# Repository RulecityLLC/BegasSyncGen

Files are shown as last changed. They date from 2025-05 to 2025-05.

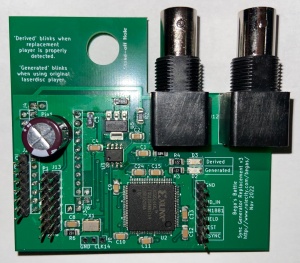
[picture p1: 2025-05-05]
BegasSyncGenPic.jpg

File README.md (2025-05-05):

# BegasSyncGen
Sync generator replacement for Bega's Battle hardware.  So that Bega's Battle will work with non-original laserdisc players, including Dexter.

# Introduction
For a full explanation, see http://www.rulecity.com/begas/ .

# PCB
I created the PCB with KiCad v5.  I tested the files on KiCad v8 and they seem to work fine.

# VHDL
I've included the VHDL source code programs I wrote for the CPLD.  I built with Xilinx ISE 14.7 which, last I checked, can be obtained for free as a linux VM that runs fine under Windows in VirtualBox.

# Bill of Materials
These are the actual spreadsheets I used when ordering parts for these PCBs.

# Support
If you need help building the VHDL code, programming the CPLDs, or having PCBs made from the KiCad files, I offer commercial support: https://www.daphne-emu.com:9443/mediawiki/index.php/CommercialSupport

--Matt Ownby

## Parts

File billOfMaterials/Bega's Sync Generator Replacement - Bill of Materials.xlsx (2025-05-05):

Quantity | Reference | Manufacturer | Manufacturer Part Number | Distributor | Dist. Part Number | Note
Surface mount
11 | C1, C2, C4, C8, C9, C10, C11, C12, C13, C15, C24 | Wurth | 885012208009 | Digi-Key | 732-8086-1-ND | 0.1 uF
2 | C3, C5 | Vishay | TL3A106K010C2000 | Digi-Key | 718-TL3A106K010C2000CT-ND | 10 uF
1 | D2 | Kingbright Company LLC | APT3216SECK/J3-PRV | Digi-Key | 754-1796-1-ND | "Generated" LED (Red)
1 | D3 | Kingbright Company LLC | APT3216SGC | Digi-Key | 754-1141-1-ND | "Derived" LED (Green)
1 | R1 |  |  | Digi-Key | P680KETR-ND | 680k Ohm
1 | R2 |  |  | Digi-Key | P75ETR-ND | 75 Ohm
2 | R3,R4 |  |  | Digi-Key | P220ETR-ND | 220 Ohm
1 | R6 |  |  | Digi-Key | P1.0KETR-ND | 1k Ohm
1 | U2 |  |  |  |  | XC95144XL-5TQG100C (XC95144XL-10TQG100C is also okay)
1 | U3 |  |  | Digi-Key | 296-47437-2-ND | LM1881
1 | U5 |  |  | Digi-Key | NCP1117LPST33T3GOSCT-ND | 3.3V voltage regulator
1 | X1 |  |  | Digi-Key | 3997-S53305T-14.31818-X-RTR-ND | S53305T-14.31818-X-R
Through hole
1 | C17 |  |  | Digi-Key | 493-15702-ND | 470uF
5 | J1,J7, J2, J8, J10+J9 |  |  | Digi-Key | 952-3302-ND | 1x12
1 | n/a |  |  | Digi-Key | S7045-ND | 1x12 socket
1 | n/a |  |  | Digi-Key | S7044-ND | 1x11 socket
4 | J3,J4,J5,J6 |  |  | Digi-Key | S7000-ND | 1x02 socket
2 | J11,J12 |  |  | Digi-Key | ACX1971-ND | BNC connector
1 | J13 |  |  | Digi-Key | 2057-PH2-14-UA-ND | JTAG Interface
Legend
Substitution is allowed
Substitution is allowed but this may change values of C3 and C5, so be careful
Substitution is allowed but clock accuracy is important

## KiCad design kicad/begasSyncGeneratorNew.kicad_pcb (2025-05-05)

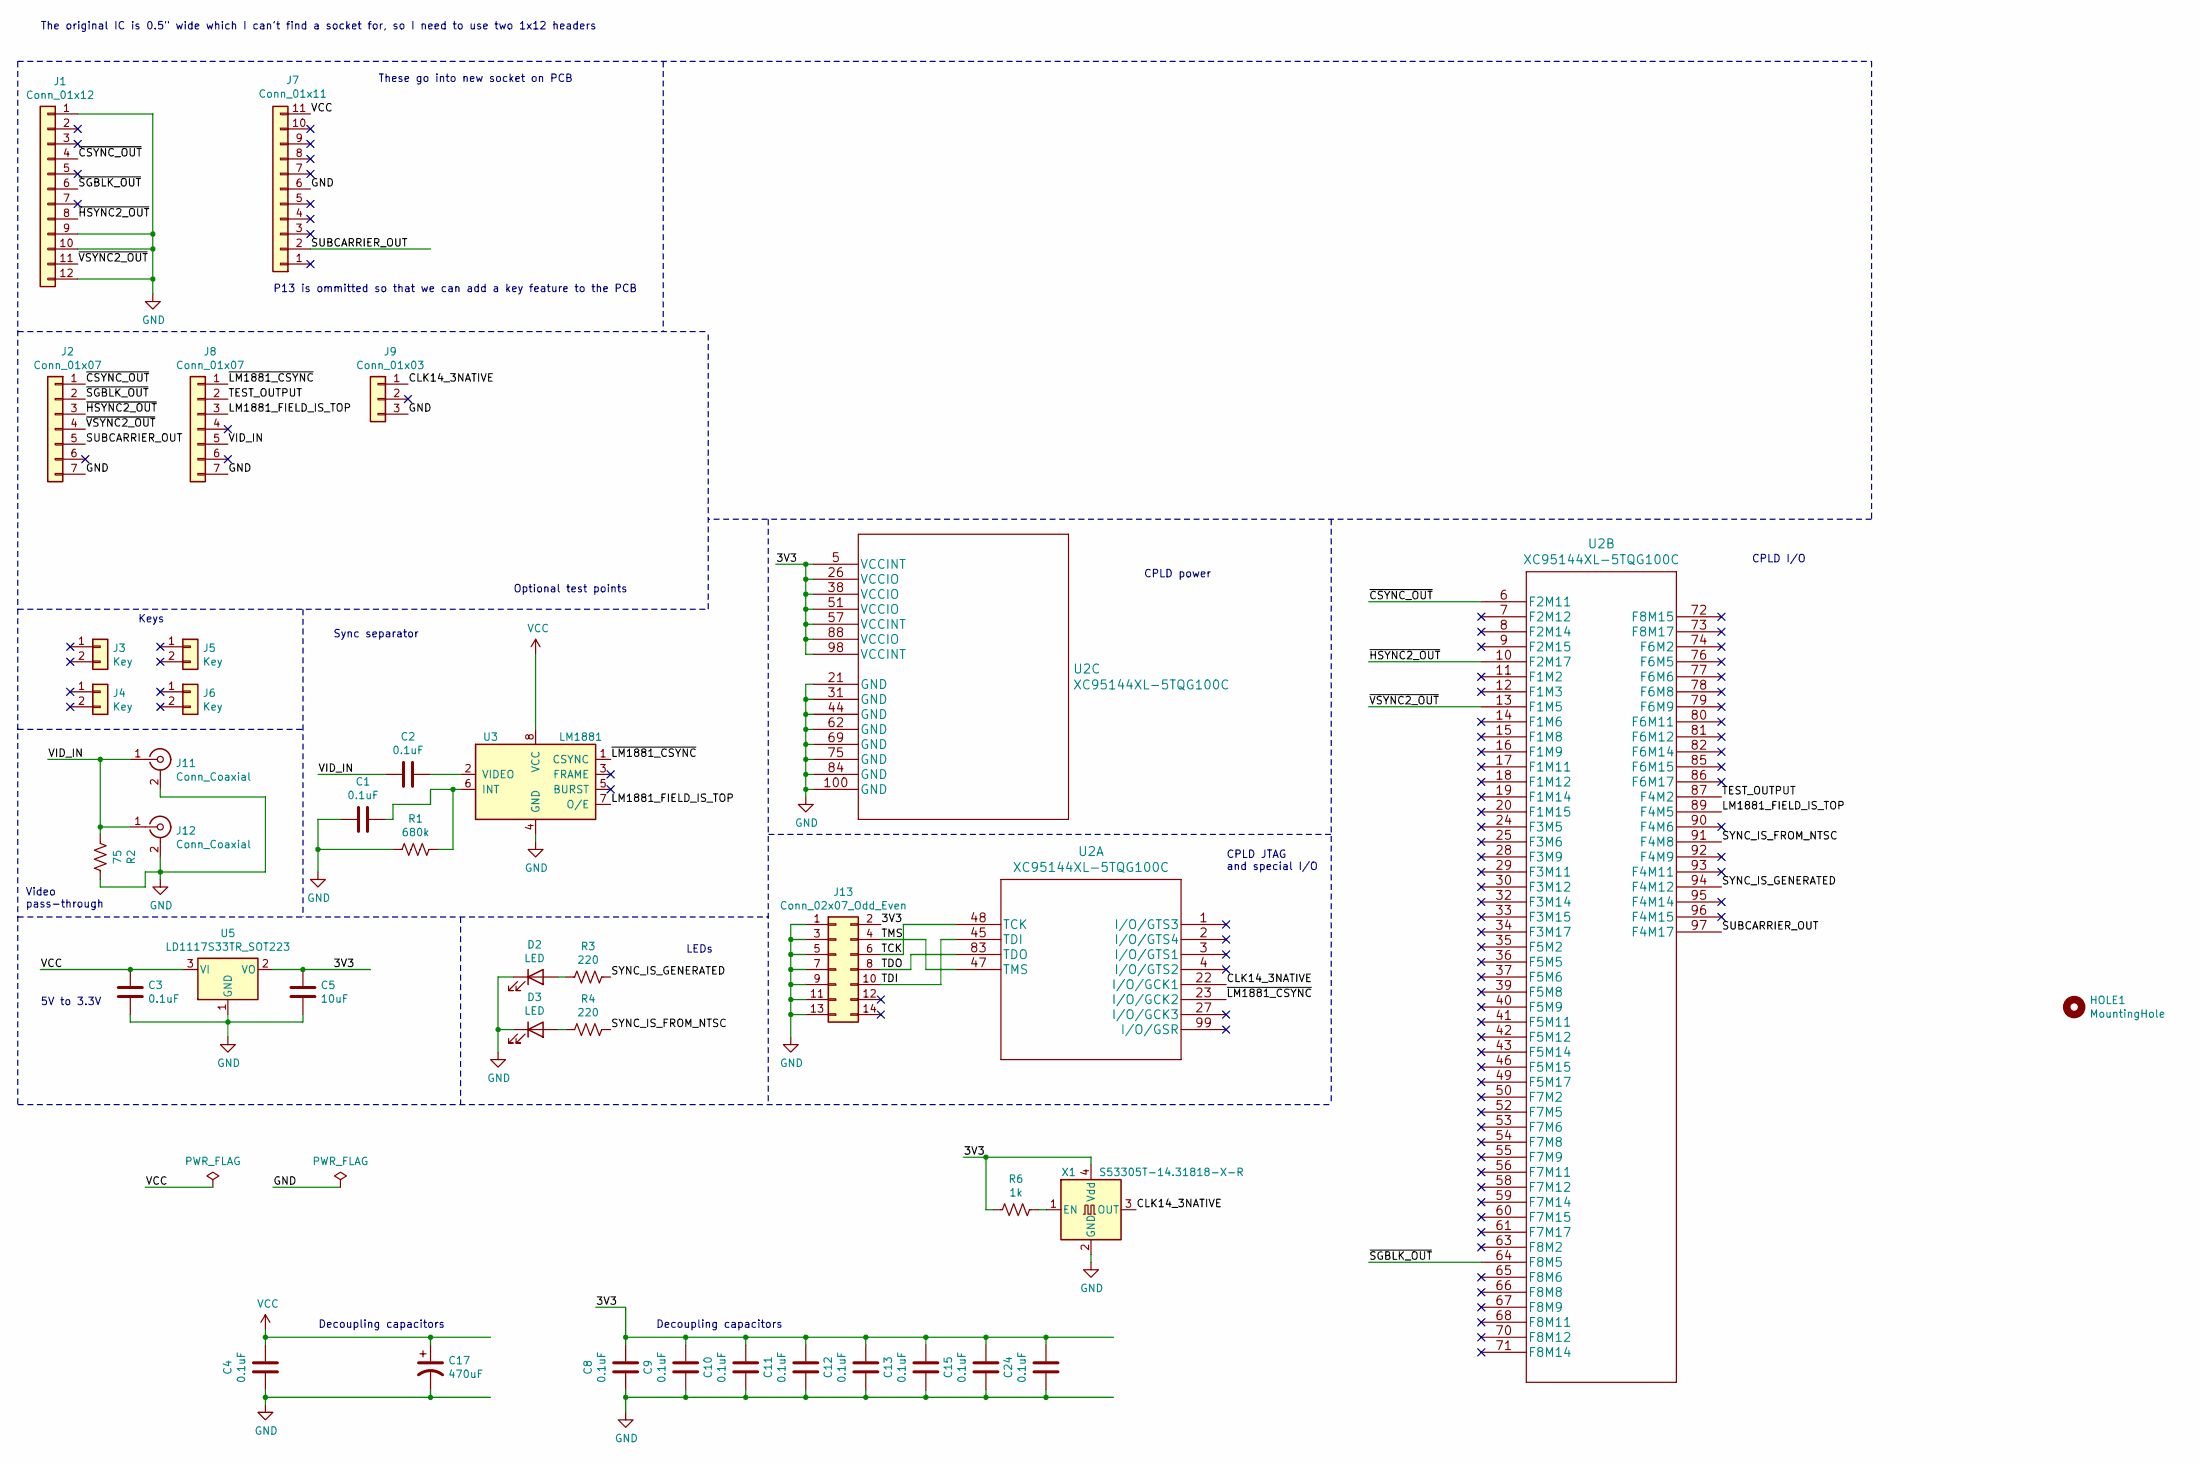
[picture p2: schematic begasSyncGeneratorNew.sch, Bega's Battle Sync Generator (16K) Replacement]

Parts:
C1, C2, C3, C4, C8, C9, C10, C11, C12, C13, C15, C24: 0.1uF; C_1206_3216Metric_Pad1.42x1.75mm_HandSolder
C5: 10uF; C_1206_3216Metric_Pad1.42x1.75mm_HandSolder
C17: 470uF; CP_Radial_D8.0mm_P5.00mm
D2, D3: LED; LED_1206_3216Metric_Pad1.42x1.75mm_HandSolder
HOLE1: MountingHole; MountingHole_8.4mm_M8
J1: Conn_01x12; PinHeader_1x12_P2.54mm_Vertical
J2, J8: Conn_01x07; PinHeader_1x07_P2.54mm_Vertical
J3, J4, J5, J6: Key; PinHeader_1x02_P2.54mm_Vertical
J7: Conn_01x11; PinHeader_1x11_P2.54mm_Vertical
J9: Conn_01x03; PinHeader_1x03_P2.54mm_Vertical
J11, J12: Conn_Coaxial; BNC_Amphenol_B6252HB-NPP3G-50_Horizontal
J13: Conn_02x07_Odd_Even; PinHeader_2x07_P2.54mm_Vertical
R1: 680k; R_1206_3216Metric_Pad1.42x1.75mm_HandSolder
R2: 75; R_1206_3216Metric_Pad1.42x1.75mm_HandSolder
R3, R4: 220; R_1206_3216Metric_Pad1.42x1.75mm_HandSolder
R6: 1k; R_1206_3216Metric_Pad1.42x1.75mm_HandSolder
U2: XC95144XL-5TQG100C
U3: LM1881; SO-8_3.9x4.9mm_P1.27mm
U5: LD1117S33TR_SOT223; SOT-223-3_TabPin2
X1: S53305T-14.31818-X-R; Oscillator_SMD_TXC_7C-4Pin_5.0x3.2mm

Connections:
/3V3: C5.1, C8.1, C9.1, C10.1, C11.1, C12.1, C13.1, C15.1, C24.1, J13.2, R6.2, U2.5 (VCCINT), U2.26 (VCCIO), U2.38 (VCCIO), U2.51 (VCCIO), U2.57 (VCCINT), U2.88 (VCCIO), U2.98 (VCCINT), U5.2 (VO), X1.4 (Vdd)
/CLK14_3NATIVE: J9.1, U2.22 (I/O/GCK1), X1.3 (OUT)
/LM1881_FIELD_IS_TOP: J8.3, U2.89 (F4M5), U3.7 (O/E)
/SUBCARRIER_OUT: J2.5, J7.2, U2.97 (F4M17)
/SYNC_IS_FROM_NTSC: R4.1, U2.91 (F4M8)
/SYNC_IS_GENERATED: R3.1, U2.94 (F4M12)
/TCK: J13.6, U2.48 (TCK)
/TDI: J13.10, U2.45 (TDI)
/TDO: J13.8, U2.83 (TDO)
/TEST_OUTPUT: J8.2, U2.87 (F4M2)
/TMS: J13.4, U2.47 (TMS)
/VID_IN: C2.2, J8.5, J11.1 (In), J12.1 (In), R2.2
/~CSYNC_OUT: J1.4, J2.1, U2.6 (F2M11)
/~HSYNC2_OUT: J1.8, J2.3, U2.10 (F2M17)
/~LM1881_CSYNC: J8.1, U2.23 (I/O/GCK2), U3.1 (CSYNC)
/~SGBLK_OUT: J1.6, J2.2, U2.64 (F8M5)
/~VSYNC2_OUT: J1.11, J2.4, U2.13 (F1M5)
GND: C1.2, C3.2, C4.2, C5.2, C8.2, C9.2, C10.2, C11.2, C12.2, C13.2, C15.2, C17.2, C24.2, D2.1 (K), D3.1 (K), J1.1, J1.9, J1.10, J1.12, J2.7, J7.6, J8.7, J9.3, J11.2 (Ext), J12.2 (Ext), J13.1, J13.3, J13.5, J13.7, J13.9, J13.11, J13.13, R1.2, R2.1, U2.21 (GND), U2.31 (GND), U2.44 (GND), U2.62 (GND), U2.69 (GND), U2.75 (GND), U2.84 (GND), U2.100 (GND), U3.4 (GND), U5.1 (GND), X1.2 (GND)
unnamed: C1.1, R1.1, U3.6 (INT)
unnamed: C2.1, U3.2 (VIDEO)
unnamed: D2.2 (A), R3.2
unnamed: D3.2 (A), R4.2
unnamed: R6.1, X1.1 (EN)
VCC: C3.1, C4.1, C17.1, J7.11, U3.8 (VCC), U5.3 (VI)

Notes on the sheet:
P13 is ommitted so that we can add a key feature to the PCB
The original IC is 0.5" wide which I can't find a socket for, so I need to use two 1x12 headers
These go into new socket on PCB
Optional test points
Sync separator
Keys
Video pass-through
CPLD power
CPLD JTAG and special I/O
5V to 3.3V
CPLD I/O
LEDs
Decoupling capacitors

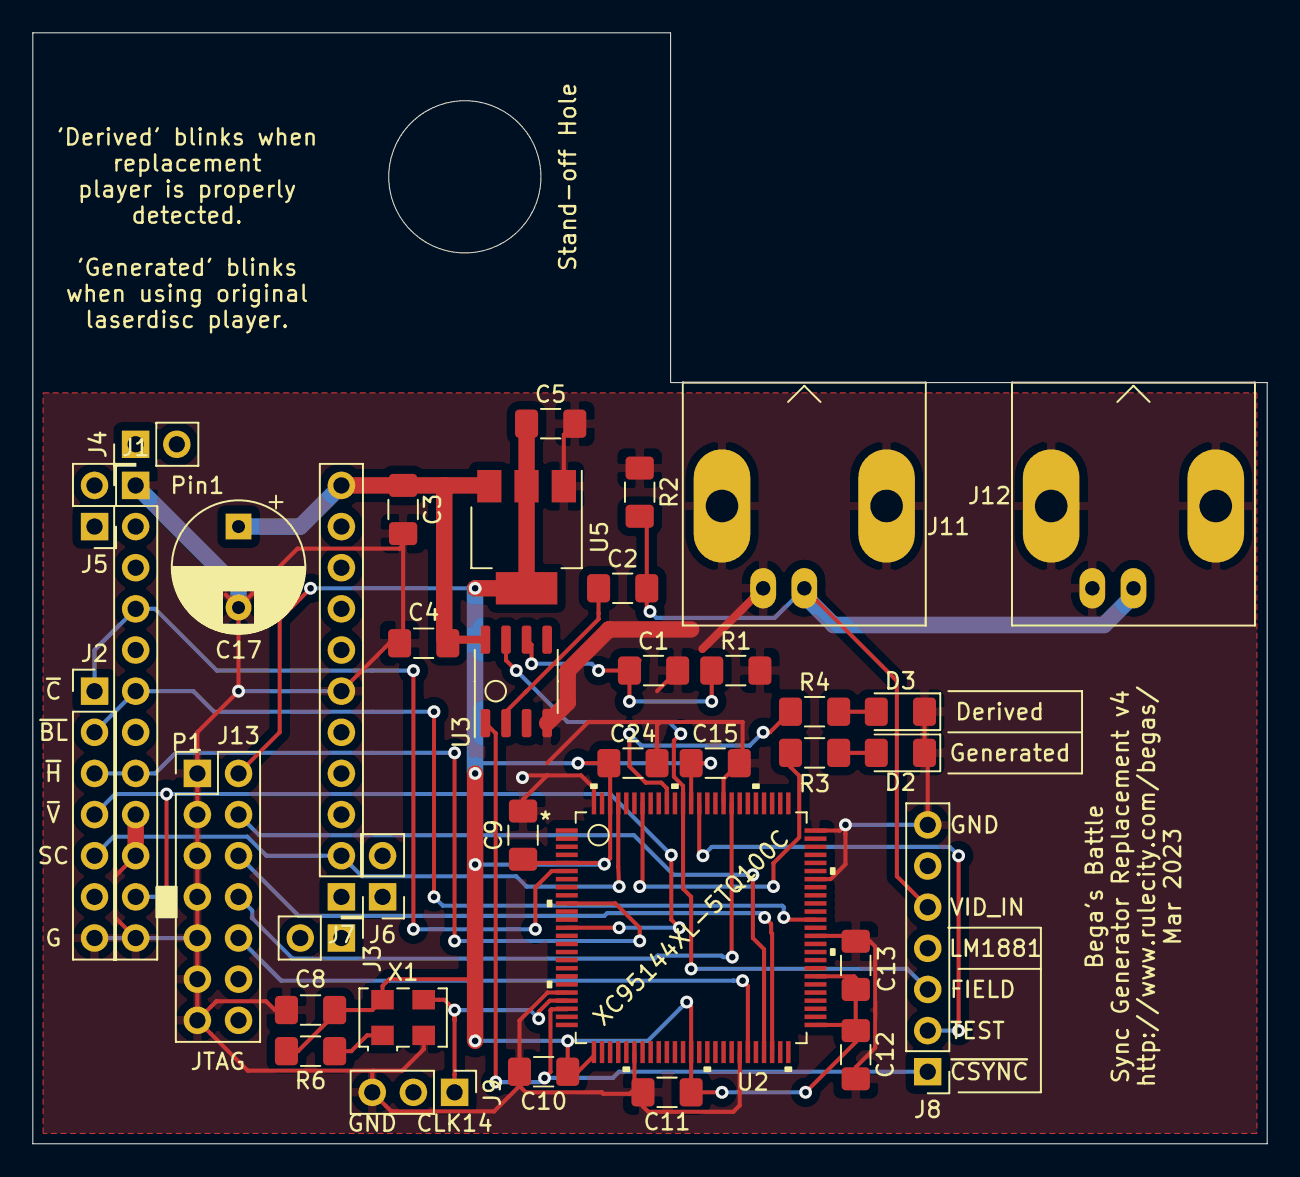
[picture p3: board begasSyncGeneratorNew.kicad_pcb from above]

Board: 2 copper layers, 76.2 x 68.6 mm, 38 parts (0 on the bottom side), 24 nets.

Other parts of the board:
Stand-off Hole: MountingHole; MountingHole_8.4mm_M8

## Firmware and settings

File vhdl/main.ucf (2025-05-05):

NET csync_prime_out			LOC="P06";
NET hsync2_prime_out			LOC="P10";
NET vsync2_prime_out			LOC="P13";
NET clk14_3native				LOC="P22" | BUFG=CLK;
NET lm1881csync_prime		LOC="P23" | BUFG=CLK;
NET sgblk_prime_out			LOC="P64";
//NET test_output				LOC="P87"	 ;
NET lm1881field_isTop		LOC="P89";
NET led_sync_is_from_ntsc	LOC="P91"	 ;
NET led_sync_is_generated	LOC="P94"	 ;
NET subcarrier_out			LOC="P97"	 ;

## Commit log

2025-05-05 added bill of materials
    [Bega's Sync Generator Replacement - Bill of Materials.xlsx]
2025-05-05 added kicad v5 files to make PCB
    [begasSyncGeneratorNew.kicad_pcb, begasSyncGeneratorNew.sch]

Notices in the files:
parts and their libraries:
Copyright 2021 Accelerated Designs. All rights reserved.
